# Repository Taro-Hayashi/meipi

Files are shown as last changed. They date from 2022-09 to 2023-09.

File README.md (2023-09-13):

# meipi
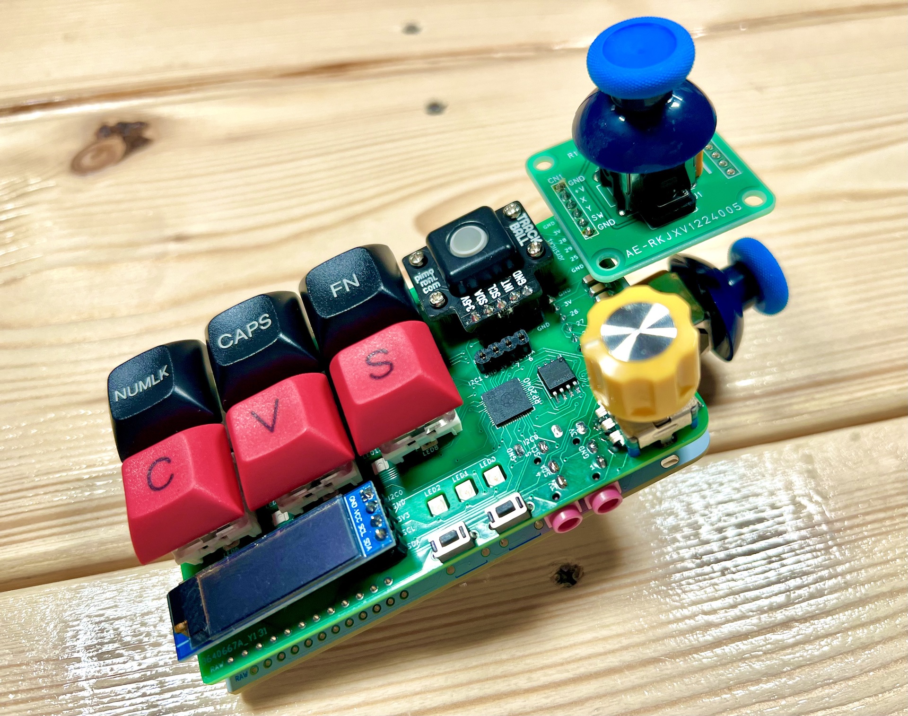
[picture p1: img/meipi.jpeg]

BOOTHで商品を購入すると付いてくることがあります。名刺代わりにお配りしているもので、組み立てるにもパーツを揃える必要がありますのでご随意にしていただければ幸いです。

## パーツリスト

### 共通パーツ
|Ref|部品名|
|-|-|
||キースイッチ|
||キーキャップ|
||CherryMXホットスワップソケット|
||1N4148W|
||MJ-4PP-9, PJ-320A|
|BOOT, RUN|3x6x4.3タクタイルスイッチ|
||Pro Micro|

### ロータリーエンコーダー
|Ref|部品名|
|-|-|
||EC11, EC12|
||ノブ|

### LED
|Ref|部品名|
|-|-|
|U1|NCP1117, ADP3338|
|LED0-12|SK6812MINI-E|

### OLED
|Ref|部品名|
|-|-|
||OLEDモジュール|
||ピンソケット 4ピン分|
||ピンヘッダ 4ピン分|

### トラックボール
|Ref|部品名|
|-|-|
||PIM447|
||3.5mmピンソケット 5ピン分|
||7mmスペーサー|
||ネジ|

### ジョイスティック
|Ref|部品名|
|-|-|
||RKJXV1224005 DIP化キット|
||キャップ|
|JOYSTICK0|L型ピンソケット 1x6（6p)|
|JOYSTICK1|ピンソケット 6ピン分|

### RP2040
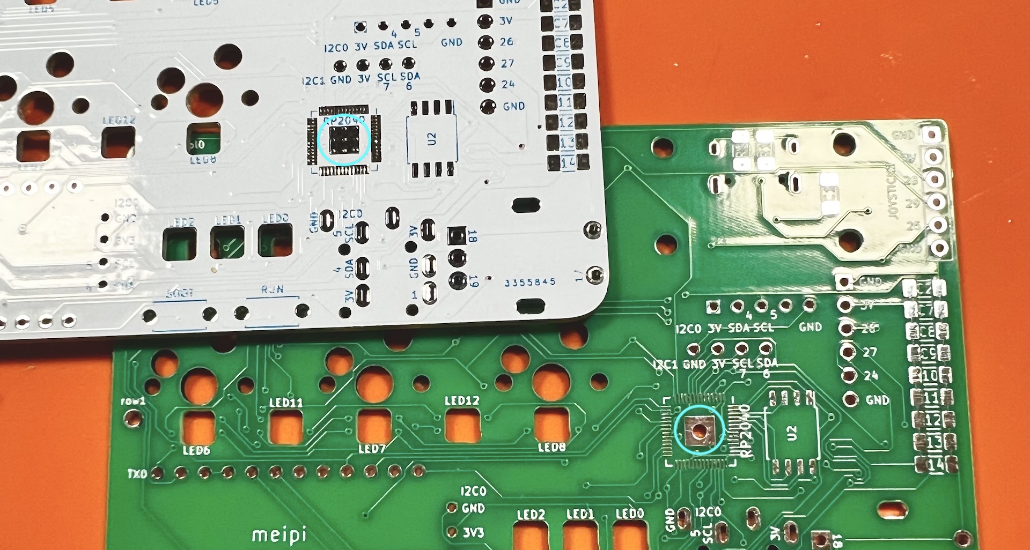
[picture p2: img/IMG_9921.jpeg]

頒布している基板には2種類あり、写真の位置に穴が空いている場合はRP2040の手はんだが可能です。
とても難しいので他のパーツより先にはんだ付けをしてください。
#### 表面実装部品
|Ref|部品名|
|-|-|
|RP2040|RP2040|
|U1|NCP1117, ADP3338|
|U2|W25Q（32MB〜）|
|USB0|USB Type-Cコネクタ 基板用|

#### 3225サイズ
|Ref|部品名|
|-|-|
|Y1|12MHz 水晶振動子|

#### 1206サイズ
|Ref|部品名|
|-|-|
|R1,2|5.1k|
|R3,4|27|
|R5|10k|
|R6-8|1k|
|C1,2|10u|
|C3|1u|
|C4,5|0.1u|
|C6|1u|
|C7-14|0.1u|
|C15,16|27p|

## ファームウェア
https://github.com/Taro-Hayashi/qmk_firmware/tree/tarohayashi/keyboards/tarohayashi/archive/meipi

### そのほか

atushi Morimoto様のフットプリントを改変、流用させていただきました。  
https://github.com/74th/rp2040-dev-board

takashicompany様のフットプリントを改変、流用させていただきました。  
https://github.com/takashicompany/tkbd-lib  
  
<br /><a rel="license" href="http://creativecommons.org/licenses/by-sa/4.0/">クリエイティブ・コモンズ 表示 - 継承 4.0 国際 ライセンス</a>の下に提供されています。

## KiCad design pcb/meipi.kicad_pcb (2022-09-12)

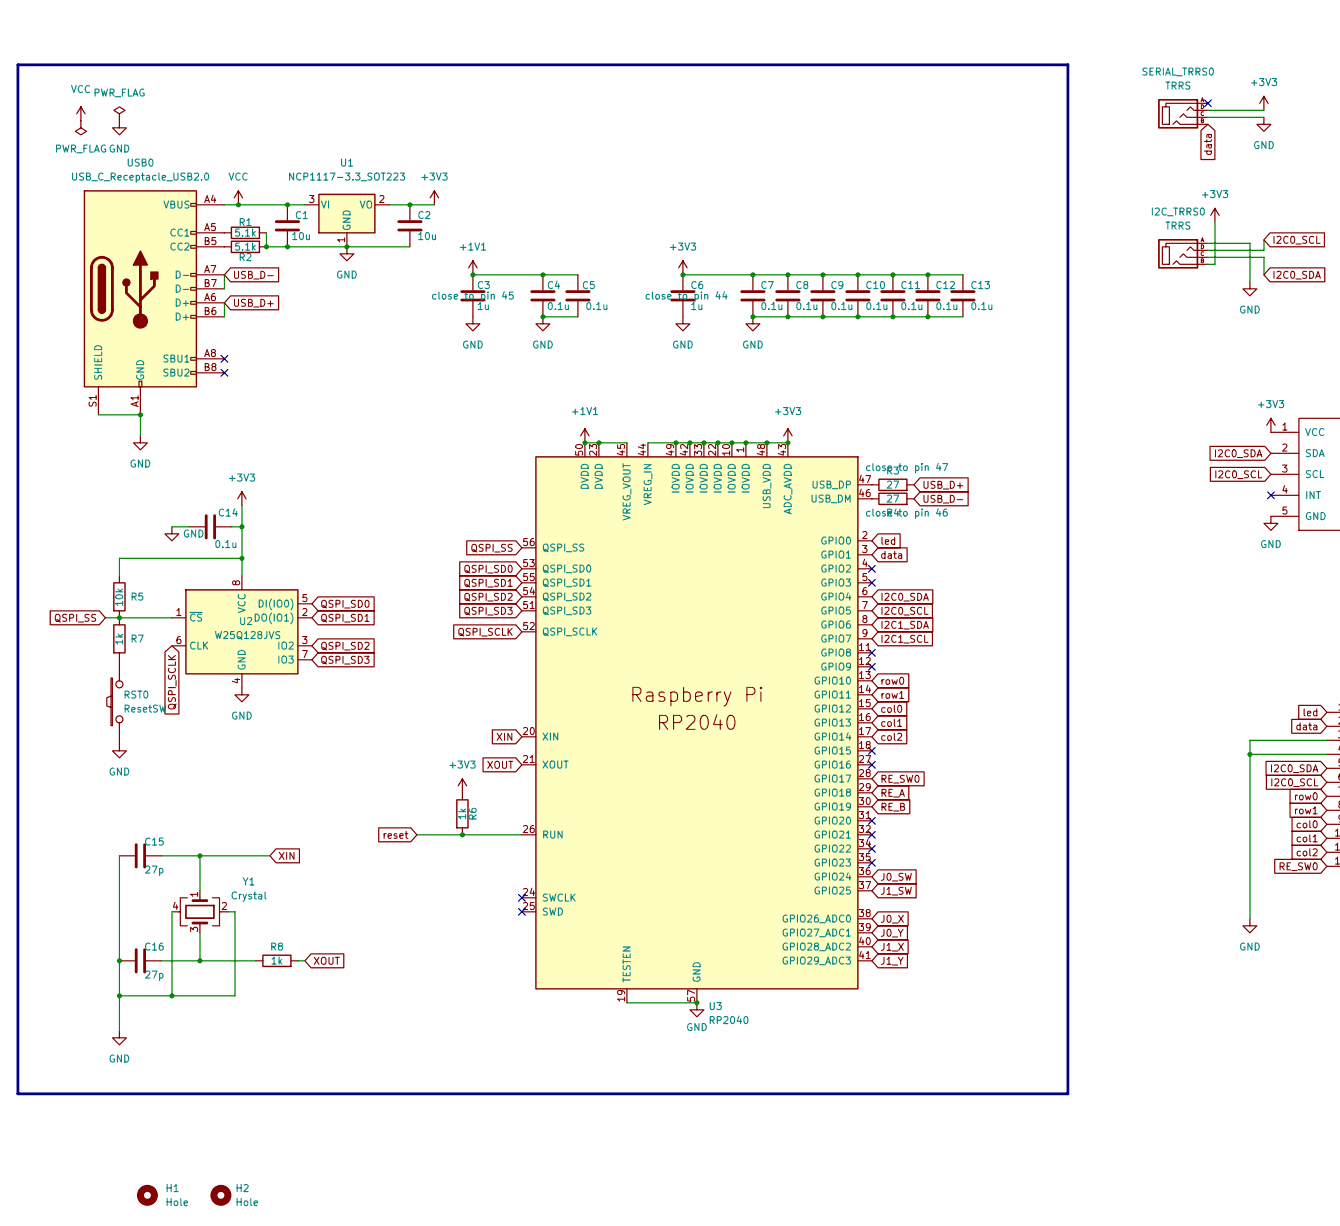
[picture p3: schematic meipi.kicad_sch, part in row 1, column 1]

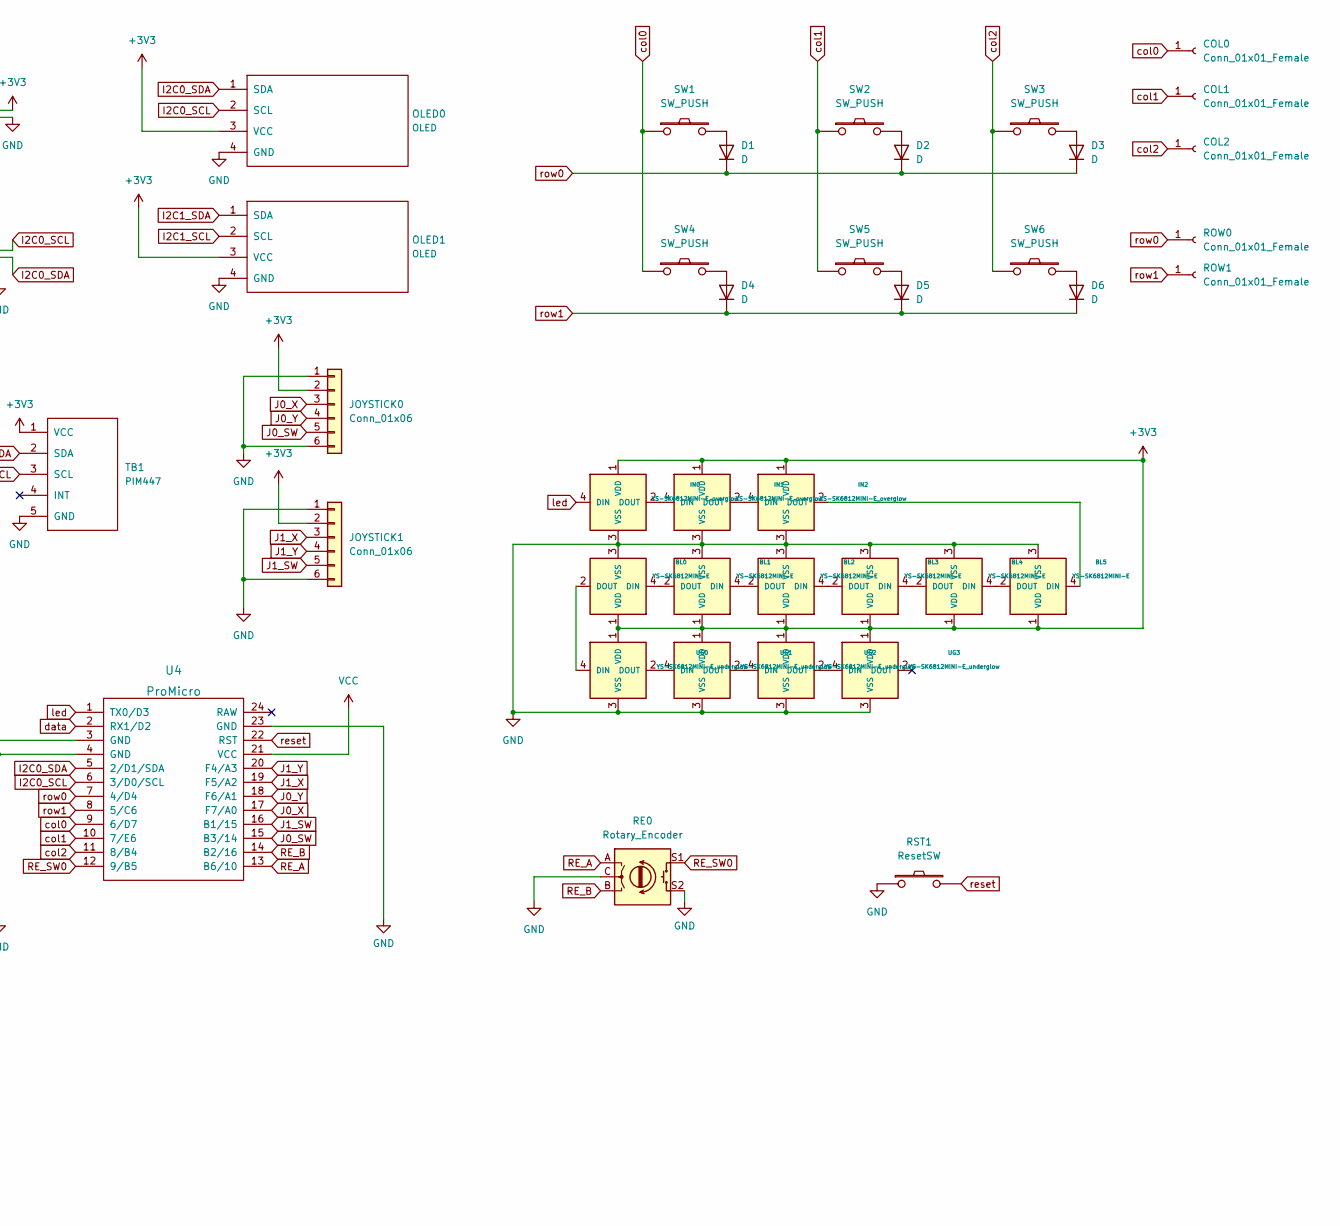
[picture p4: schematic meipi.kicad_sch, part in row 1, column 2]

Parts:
BL0, BL1, BL2, BL3, BL4, BL5: YS-SK6812MINI-E
C1, C2: 10u; C_1206_3216_SMD
C3, C6: 1u; C_1206_3216_SMD
C4, C5, C7, C8, C9, C10, C11, C12, C13, C14: 0.1u; C_1206_3216_SMD
C15, C16: 27p; C_1206_3216_SMD
COL0, COL1, COL2: Conn_01x01_Female; Conn_1.3mm_M2
D1, D2, D3, D4, D5, D6: D; Diode_SMD
H1, H2: Hole; Hole_2.2mm_M2
I2C_TRRS0: TRRS
IN0, IN1, IN2: YS-SK6812MINI-E_overglow; YS-SK6812MINI-E
JOYSTICK0: Conn_01x06; PinSocket_1x06_P2.54mm_Horizontal
JOYSTICK1: Conn_01x06; PinHeader_1x06_P2.54mm_Vertical
OLED0, OLED1: OLED
R1, R2: 5.1k; R_1206_3216_SMD
R3, R4: 27; R_1206_3216_SMD
R5: 10k; R_1206_3216_SMD
R6, R7, R8: 1k; R_1206_3216_SMD
RE0: Rotary_Encoder; RotaryEncoder
ROW0, ROW1: Conn_01x01_Female; Conn_1.3mm_M2
RST0, RST1: ResetSW
SERIAL_TRRS0: TRRS
SW1, SW2, SW3, SW4, SW5, SW6: SW_PUSH; MXOnly-1U-Hotswap
TB1: PIM447
U1: NCP1117-3.3_SOT223; SOT-223-3_TabPin2
U2: W25Q128JVS; SOIC-8_5.23x5.23mm_P1.27mm
U3: RP2040; RP2040-QFN-56
U4: ProMicro; ProMicro_back_usd
UG0, UG1, UG2, UG3: YS-SK6812MINI-E_underglow; YS-SK6812MINI-E_Undergrow
USB0: USB_C_Receptacle_USB2.0
Y1: Crystal; Crystal_3225_SMD

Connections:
+1V1: C3.1, C4.1, C5.1, U3.23 (DVDD), U3.45 (VREG_VOUT), U3.50 (DVDD); also elsewhere on the board
+3V3: BL0.1 (VDD), BL1.1 (VDD), BL2.1 (VDD), BL3.1 (VDD), BL4.1 (VDD), BL5.1 (VDD), C2.1, C6.1, C7.1, C8.1, C9.1, C10.1, C11.1, C12.1, C13.1, C14.1, I2C_TRRS0.B, IN0.1 (VDD), IN1.1 (VDD), IN2.1 (VDD), JOYSTICK0.2, JOYSTICK1.2, OLED0.3 (VCC), OLED1.3 (VCC), R5.1, R6.1, SERIAL_TRRS0.D, TB1.1 (VCC), U1.2 (VO), U2.8 (VCC), U3.1 (IOVDD), U3.10 (IOVDD), U3.22 (IOVDD), U3.33 (IOVDD), U3.42 (IOVDD), U3.43 (ADC_AVDD), U3.44 (VREG_IN), U3.48 (USB_VDD), U3.49 (IOVDD), UG0.1 (VDD), UG1.1 (VDD), UG2.1 (VDD), UG3.1 (VDD); also elsewhere on the board
GND: BL0.3 (VSS), BL1.3 (VSS), BL2.3 (VSS), BL3.3 (VSS), BL4.3 (VSS), BL5.3 (VSS), C1.1, C2.2, C3.2, C4.2, C5.2, C6.2, C7.2, C8.2, C9.2, C10.2, C11.2, C12.2, C13.2, C14.2, C15.1, C16.1, I2C_TRRS0.A, IN0.3 (VSS), IN1.3 (VSS), IN2.3 (VSS), JOYSTICK0.1, JOYSTICK0.6, JOYSTICK1.1, JOYSTICK1.6, OLED0.4 (GND), OLED1.4 (GND), R1.2, R2.2, RE0.C, RE0.S2, RST0.1, RST1.1, SERIAL_TRRS0.C, TB1.5 (GND), U1.1 (GND), U2.4 (GND), U3.19 (TESTEN), U3.57 (GND), U4.3 (GND), U4.4 (GND), U4.23 (GND), UG0.3 (VSS), UG1.3 (VSS), UG2.3 (VSS), UG3.3 (VSS), USB0.A1 (GND), USB0.A12 (GND), USB0.B1 (GND), USB0.B12 (GND), USB0.S1 (SHIELD), Y1.2, Y1.4; also elsewhere on the board
I2C0_SCL: I2C_TRRS0.D, OLED0.2 (SCL), TB1.3 (SCL), U3.7 (GPIO5), U4.6 (3/D0/SCL); also elsewhere on the board
I2C0_SDA: I2C_TRRS0.C, OLED0.1 (SDA), TB1.2 (SDA), U3.6 (GPIO4), U4.5 (2/D1/SDA); also elsewhere on the board
I2C1_SCL: OLED1.2 (SCL), U3.9 (GPIO7); also elsewhere on the board
I2C1_SDA: OLED1.1 (SDA), U3.8 (GPIO6); also elsewhere on the board
J0_SW: JOYSTICK0.5, U3.36 (GPIO24), U4.15 (B3/14); also elsewhere on the board
J0_X: JOYSTICK0.3, U3.38 (GPIO26_ADC0), U4.17 (F7/A0); also elsewhere on the board
J0_Y: JOYSTICK0.4, U3.39 (GPIO27_ADC1), U4.18 (F6/A1); also elsewhere on the board
J1_SW: JOYSTICK1.5, U3.37 (GPIO25), U4.16 (B1/15); also elsewhere on the board
J1_X: JOYSTICK1.3, U3.40 (GPIO28_ADC2), U4.19 (F5/A2); also elsewhere on the board
J1_Y: JOYSTICK1.4, U3.41 (GPIO29_ADC3), U4.20 (F4/A3); also elsewhere on the board
unnamed: BL0.2 (DOUT), UG0.4 (DIN)
unnamed: BL0.4 (DIN), BL1.2 (DOUT)
unnamed: BL1.4 (DIN), BL2.2 (DOUT)
unnamed: BL2.4 (DIN), BL3.2 (DOUT)
unnamed: BL3.4 (DIN), BL4.2 (DOUT)
unnamed: BL4.4 (DIN), BL5.2 (DOUT)
unnamed: BL5.4 (DIN), IN2.2 (DOUT)
unnamed: C16.2, R8.1, Y1.3
unnamed: D1.2 (A), SW1.2
unnamed: D2.2 (A), SW2.2
unnamed: D3.2 (A), SW3.2
unnamed: D4.2 (A), SW4.2
unnamed: D5.2 (A), SW5.2
unnamed: D6.2 (A), SW6.2
unnamed: IN0.2 (DOUT), IN1.4 (DIN)
unnamed: IN1.2 (DOUT), IN2.4 (DIN)
unnamed 29: R3.1, U3.47 (USB_DP); also elsewhere on the board
unnamed 30: R4.1, U3.46 (USB_DM); also elsewhere on the board
unnamed: R7.2, RST0.2
unnamed: UG0.2 (DOUT), UG1.4 (DIN)
unnamed: UG1.2 (DOUT), UG2.4 (DIN)
unnamed: UG2.2 (DOUT), UG3.4 (DIN)
unnamed: R1.1, USB0.A5 (CC1)
unnamed: R2.1, USB0.B5 (CC2)
QSPI_SCLK: U2.6 (CLK), U3.52 (QSPI_SCLK); also elsewhere on the board
QSPI_SD0: U2.5 (DI(IO0)), U3.53 (QSPI_SD0); also elsewhere on the board
QSPI_SD1: U2.2 (DO(IO1)), U3.55 (QSPI_SD1); also elsewhere on the board
QSPI_SD2: U2.3 (IO2), U3.54 (QSPI_SD2); also elsewhere on the board
QSPI_SD3: U2.7 (IO3), U3.51 (QSPI_SD3); also elsewhere on the board
QSPI_SS: R5.2, R7.1, U2.1 (~CS), U3.56 (QSPI_SS); also elsewhere on the board
RE_A: RE0.A, U3.29 (GPIO18), U4.13 (B6/10); also elsewhere on the board
RE_B: RE0.B, U3.30 (GPIO19), U4.14 (B2/16); also elsewhere on the board
RE_SW0: RE0.S1, U3.28 (GPIO17), U4.12 (9/B5); also elsewhere on the board
USB_D+: R3.2, USB0.A6 (D+), USB0.B6 (D+)
USB_D-: R4.2, USB0.A7 (D-), USB0.B7 (D-)
VCC: C1.2, U1.3 (VI), U4.21 (VCC), USB0.A4 (VBUS), USB0.A9 (VBUS), USB0.B4 (VBUS), USB0.B9 (VBUS)
XIN: C15.2, U3.20 (XIN), Y1.1; also elsewhere on the board
XOUT: R8.2, U3.21 (XOUT); also elsewhere on the board
col0: COL0.1, SW1.1, SW4.1, U3.15 (GPIO12), U4.9 (6/D7); also elsewhere on the board
col1: COL1.1, SW2.1, SW5.1, U3.16 (GPIO13), U4.10 (7/E6); also elsewhere on the board
col2: COL2.1, SW3.1, SW6.1, U3.17 (GPIO14), U4.11 (8/B4); also elsewhere on the board
data: SERIAL_TRRS0.B, U3.3 (GPIO1), U4.2 (RX1/D2); also elsewhere on the board
led: IN0.4 (DIN), U3.2 (GPIO0), U4.1 (TX0/D3); also elsewhere on the board
reset: R6.2, RST1.2, U3.26 (RUN), U4.22 (RST); also elsewhere on the board
row0: D1.1 (K), D2.1 (K), D3.1 (K), ROW0.1, U3.13 (GPIO10), U4.7 (4/D4); also elsewhere on the board
row1: D4.1 (K), D5.1 (K), D6.1 (K), ROW1.1, U3.14 (GPIO11), U4.8 (5/C6); also elsewhere on the board

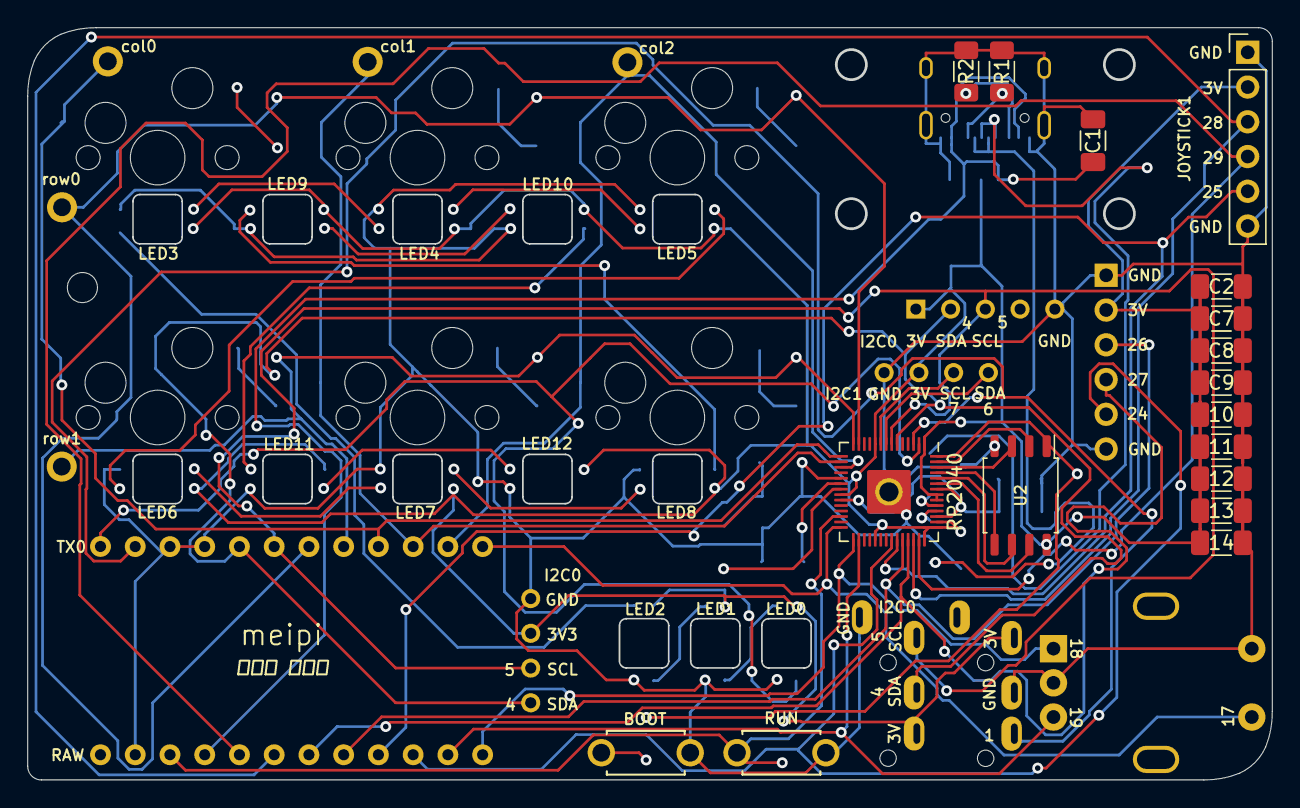
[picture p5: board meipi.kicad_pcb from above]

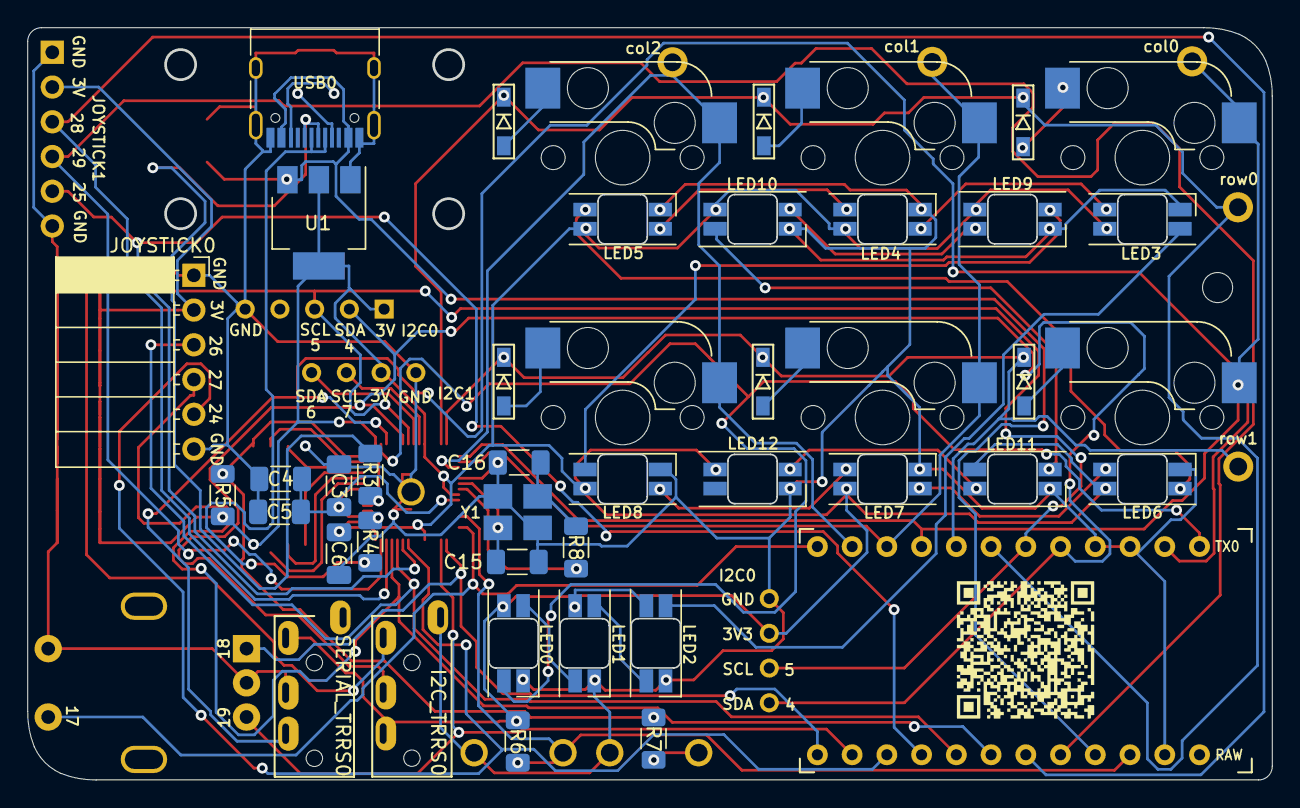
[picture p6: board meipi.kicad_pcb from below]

Board: 2 copper layers, 91.0 x 55.0 mm, 71 parts (33 on the bottom side), 59 nets.

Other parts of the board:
10, 11, 12, 13, 14: 0.1u; C_1206_3216_SMD
RP2040: RP2040; RP2040-QFN-56

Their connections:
+1V1: RP2040.23 (DVDD), RP2040.45 (VREG_VOUT), RP2040.50 (DVDD); also elsewhere on the board
+3V3: 10.1, 11.1, 12.1, 13.1, 14.1, RP2040.1 (IOVDD), RP2040.10 (IOVDD), RP2040.22 (IOVDD), RP2040.33 (IOVDD), RP2040.42 (IOVDD), RP2040.43 (ADC_AVDD), RP2040.44 (VREG_IN), RP2040.48 (USB_VDD), RP2040.49 (IOVDD); also elsewhere on the board
GND: 10.2, 11.2, 12.2, 13.2, 14.2, RP2040.19 (TESTEN), RP2040.57 (GND); also elsewhere on the board
I2C0_SCL: RP2040.7 (GPIO5); also elsewhere on the board
I2C0_SDA: RP2040.6 (GPIO4); also elsewhere on the board
I2C1_SCL: RP2040.9 (GPIO7); also elsewhere on the board
I2C1_SDA: RP2040.8 (GPIO6); also elsewhere on the board
J0_SW: RP2040.36 (GPIO24); also elsewhere on the board
J0_X: RP2040.38 (GPIO26_ADC0); also elsewhere on the board
J0_Y: RP2040.39 (GPIO27_ADC1); also elsewhere on the board
J1_SW: RP2040.37 (GPIO25); also elsewhere on the board
J1_X: RP2040.40 (GPIO28_ADC2); also elsewhere on the board
J1_Y: RP2040.41 (GPIO29_ADC3); also elsewhere on the board
unnamed 29: RP2040.47 (USB_DP); also elsewhere on the board
unnamed 30: RP2040.46 (USB_DM); also elsewhere on the board
QSPI_SCLK: RP2040.52 (QSPI_SCLK); also elsewhere on the board
QSPI_SD0: RP2040.53 (QSPI_SD0); also elsewhere on the board
QSPI_SD1: RP2040.55 (QSPI_SD1); also elsewhere on the board
QSPI_SD2: RP2040.54 (QSPI_SD2); also elsewhere on the board
QSPI_SD3: RP2040.51 (QSPI_SD3); also elsewhere on the board
QSPI_SS: RP2040.56 (QSPI_SS); also elsewhere on the board
RE_A: RP2040.29 (GPIO18); also elsewhere on the board
RE_B: RP2040.30 (GPIO19); also elsewhere on the board
RE_SW0: RP2040.28 (GPIO17); also elsewhere on the board
XIN: RP2040.20 (XIN); also elsewhere on the board
XOUT: RP2040.21 (XOUT); also elsewhere on the board
col0: RP2040.15 (GPIO12); also elsewhere on the board
col1: RP2040.16 (GPIO13); also elsewhere on the board
col2: RP2040.17 (GPIO14); also elsewhere on the board
data: RP2040.3 (GPIO1); also elsewhere on the board
led: RP2040.2 (GPIO0); also elsewhere on the board
reset: RP2040.26 (RUN); also elsewhere on the board
row0: RP2040.13 (GPIO10); also elsewhere on the board
row1: RP2040.14 (GPIO11); also elsewhere on the board

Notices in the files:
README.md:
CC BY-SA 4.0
